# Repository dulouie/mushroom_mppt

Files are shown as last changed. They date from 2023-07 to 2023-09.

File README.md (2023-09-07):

# Mushroom MPPT Controller
The mushroom controller, is a micropython powered mppt solar optimizer to investigate different algorithms.

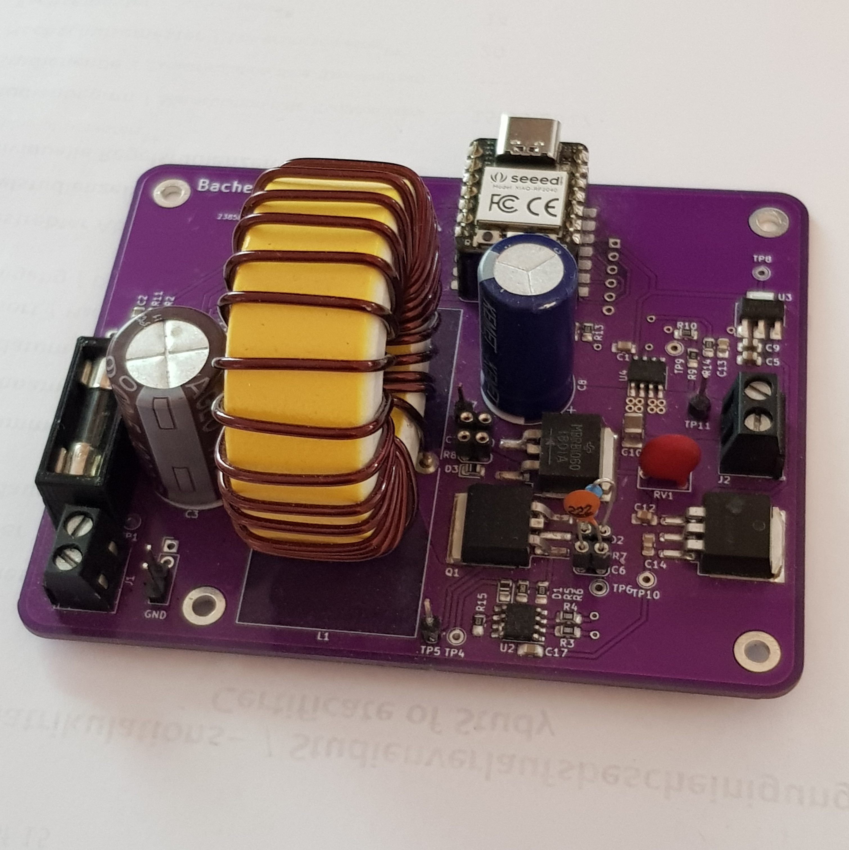
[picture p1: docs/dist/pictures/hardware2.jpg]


You can find a great overview of the project on this [slides](https://dulouie.github.io/mushroom_mppt/) or read the project [documentation](https://dulouie.github.io/mushroom_mppt_doc/).

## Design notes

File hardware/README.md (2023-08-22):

# Hardware

Here you will find the information to build the Mushroom MPPT controller. The schematic and the board layout is a KiCAD 7 project. 

Layout

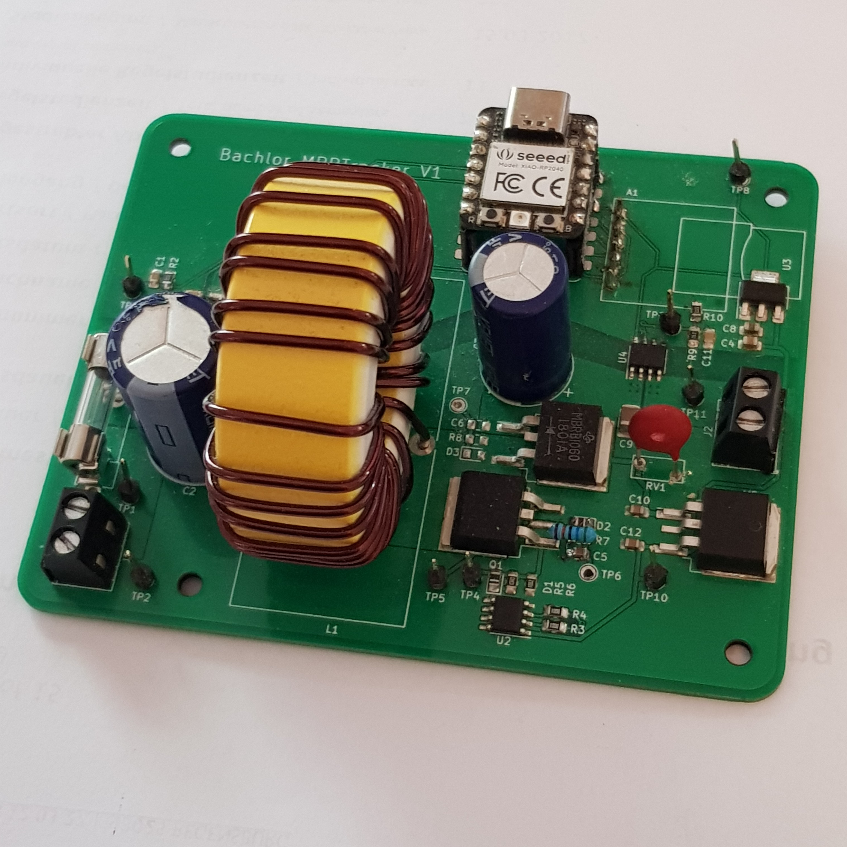
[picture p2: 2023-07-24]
docs/dist/pictures/hardware1.jpg

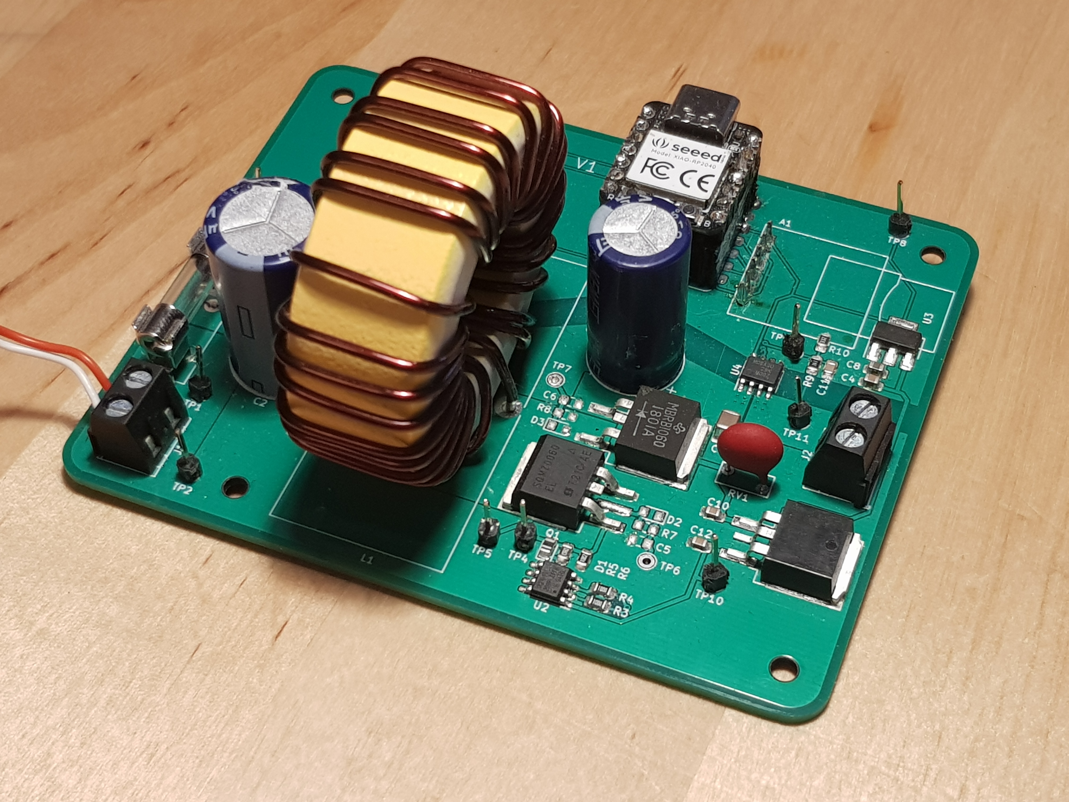
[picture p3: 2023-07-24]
slides/dist/pictures/hardware_alt.jpg

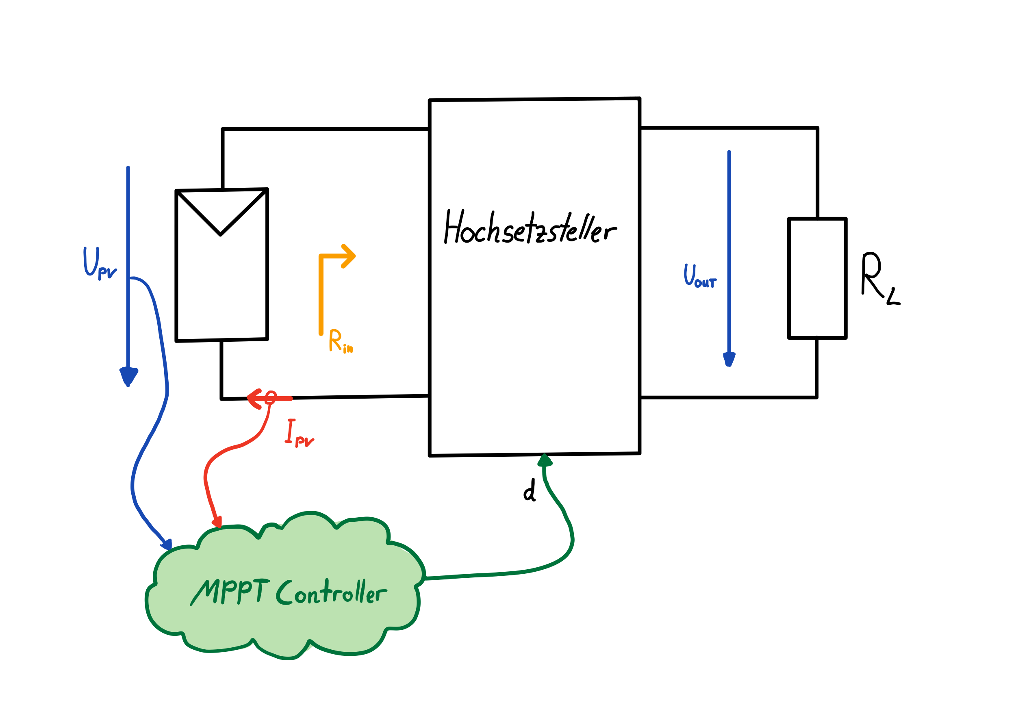
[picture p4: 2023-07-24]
docs/dist/pictures/konzept5.png

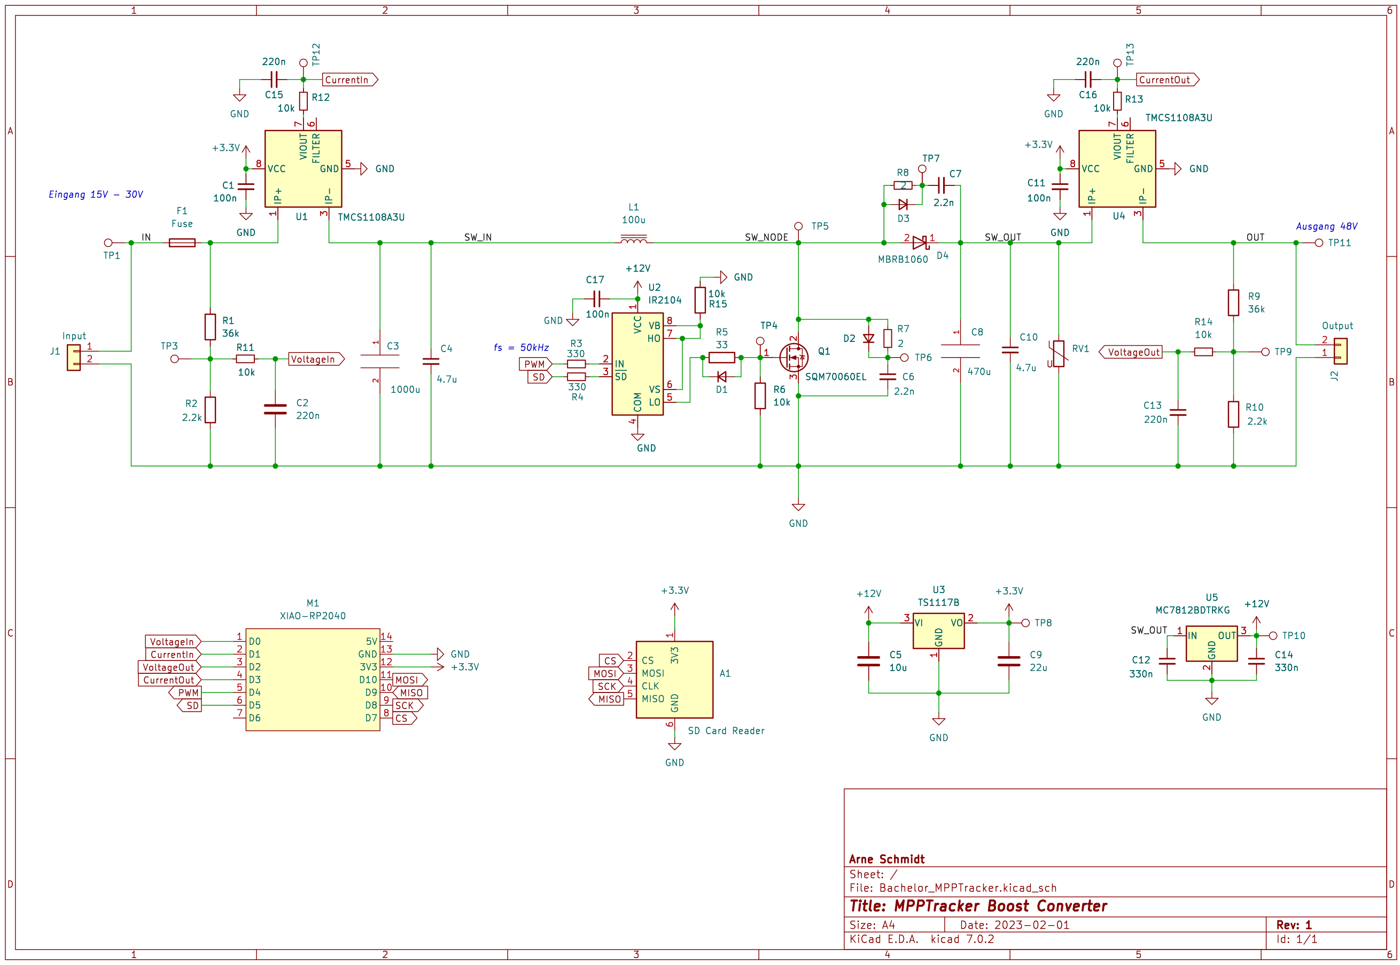
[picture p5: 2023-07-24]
docs/dist/pictures/schaltplan_final.png

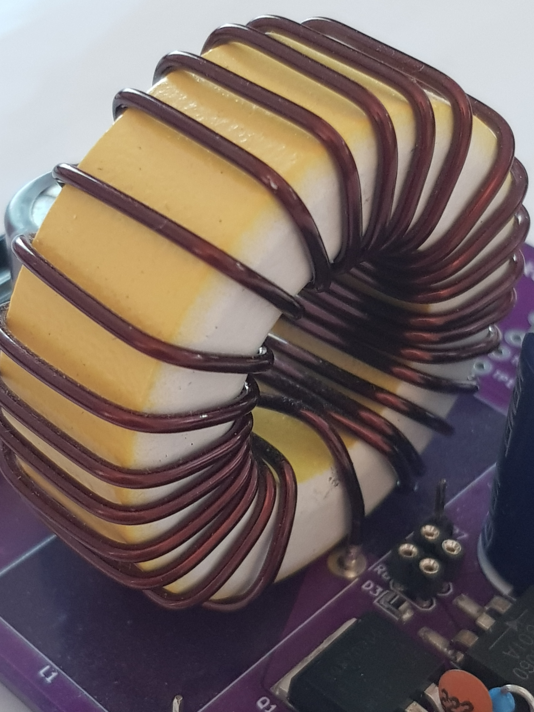
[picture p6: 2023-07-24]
docs/dist/pictures/spule.jpg

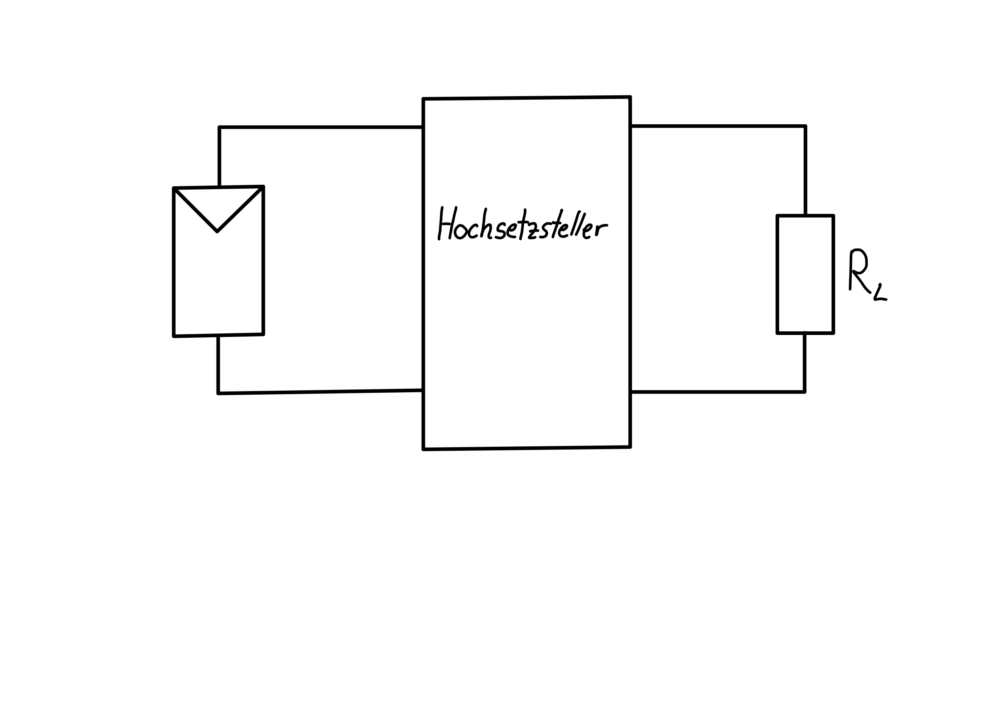
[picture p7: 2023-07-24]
docs/dist/pictures/konzept3.png

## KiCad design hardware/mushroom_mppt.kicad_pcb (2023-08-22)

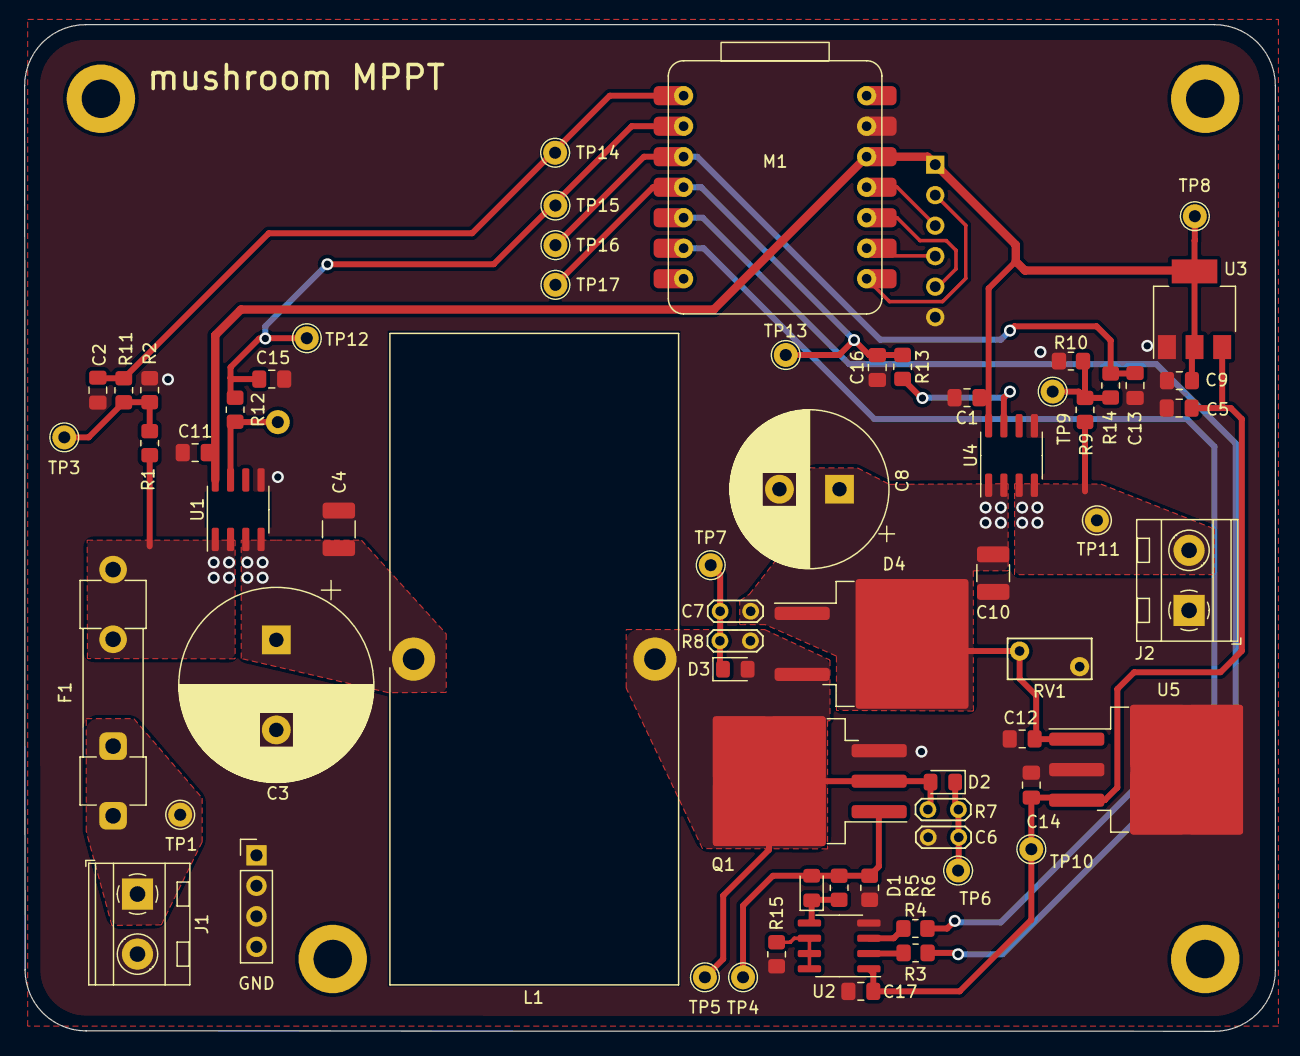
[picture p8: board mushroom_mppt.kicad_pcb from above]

Board: 2 copper layers, 104.1 x 83.8 mm, 66 parts (1 on the bottom side), 30 nets.

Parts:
A1: SD Card Reader; SD_Card_Module
C1, C11, C17: 0.1u; C_0805_2012Metric_Pad1.18x1.45mm_HandSolder
C2, C13, C15, C16: 220n; C_0805_2012Metric_Pad1.18x1.45mm_HandSolder
C3: 1000u; CP_Radial_D16.0mm_P7.50mm
C4: 4,7u; C_1210_3225Metric_Pad1.33x2.70mm_HandSolder
C5: 10u; C_0805_2012Metric_Pad1.18x1.45mm_HandSolder
C6, C7: C_snubber; TestPoint_2Pads_Pitch2.54mm_Drill0.8mm
C8: 470u; CP_Radial_D13.0mm_P5.00mm
C9: 22u; C_0805_2012Metric_Pad1.18x1.45mm_HandSolder
C10: 4.7u; C_1210_3225Metric_Pad1.33x2.70mm_HandSolder
C12, C14: 0.33u; C_0805_2012Metric_Pad1.18x1.45mm_HandSolder
D1: D_gatedriver; D_0805_2012Metric_Pad1.15x1.40mm_HandSolder
D2, D3: snubber; D_0805_2012Metric_Pad1.15x1.40mm_HandSolder
D4: MBRB1060; TO-263-2_TabPin1
F1: Fuse; Fuseholder_Clip-5x20mm_Littelfuse_520_Inline_P20.50x5.80mm_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
GND: TestPoint; PinHeader_1x04_P2.54mm_Vertical
J1: Input; TerminalBlock_MetzConnect_Type094_RT03502HBLU_1x02_P5.00mm_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
J2: Output; TerminalBlock_MetzConnect_Type094_RT03502HBLU_1x02_P5.00mm_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
L1: 100u; L_Toroid_Vertical_L54.0mm_W23.8mm_P20.10mm_Bourns_5700
M1: XIAO-RP2040
Q1: SQM70060EL; TO-263-3_TabPin2
R1, R9: 36k; R_0805_2012Metric_Pad1.20x1.40mm_HandSolder
R2, R10: 2.2k; R_0805_2012Metric_Pad1.20x1.40mm_HandSolder
R3, R4: 100; R_0805_2012Metric_Pad1.20x1.40mm_HandSolder
R5: 10; R_0805_2012Metric_Pad1.20x1.40mm_HandSolder
R6, R11, R12, R13, R14, R15: 10k; R_0805_2012Metric_Pad1.20x1.40mm_HandSolder
R7, R8: snubber; TestPoint_2Pads_Pitch2.54mm_Drill0.8mm
RV1: type="I" model="Varistor" lib=""; RV_Disc_D7mm_W3.4mm_P5mm
TP1, TP3, TP4, TP5, TP6, TP7, TP8, TP9, TP10, TP11, TP12, TP13, TP14, TP15, TP16, TP17: TestPoint; TestPoint_THTPad_D2.0mm_Drill1.0mm
U1, U4: TMCS1108A3U; SOIC-8_3.9x4.9mm_P1.27mm
U2: IR2104; SOIC-8_3.9x4.9mm_P1.27mm
U3: TS1117B; SOT-223-3_TabPin2
U5: MC7812BDTRKG; TO-263-3_TabPin2

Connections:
+3.3V: A1.1 (3V3), C1.1, C9.1, C11.1, M1.12 (3V3), TP8.1, U1.8 (VCC), U3.2 (VO), U4.8 (VCC)
+12V: C5.1, C14.1, C17.1, TP10.1, U2.1 (VCC), U3.3 (VI), U5.3 (OUT)
/OUT: J2.2, R9.1, TP11.1, U4.3 (IP-), U4.4 (IP-)
/SW_IN: C3.1, C4.1, L1.1, U1.3 (IP-), U1.4 (IP-)
/SW_NODE: D2.2 (A), D3.2 (A), D4.2 (A), L1.2, Q1.2 (D), R7.1, R8.1, TP5.1
/SW_OUT: C7.2, C8.1, C10.1, C12.1, D4.1 (K), RV1.1, U4.1 (IP+), U4.2 (IP+), U5.1 (IN)
CS: A1.2 (CS), M1.8 (D7)
CurrentIn: C15.2, M1.2 (D1), R12.1, TP12.1, TP15.1
CurrentOut: C16.2, M1.4 (D3), R13.1, TP13.1, TP17.1
GND: A1.6 (GND), C1.2, C2.2, C3.2, C4.2, C5.2, C6.2, C8.2, C9.2, C10.2, C11.2, C12.2, C13.2, C14.2, C15.1, C16.1, C17.2, GND.1, GND.2, GND.3, GND.4, J1.2, J2.1, M1.13 (GND), Q1.3 (S), R2.2, R6.2, R10.2, R15.1, RV1.2, U1.5 (GND), U2.4 (COM), U3.1 (GND), U4.5 (GND), U5.2 (GND)
IN: F1.1, J1.1, TP1.1
MISO: A1.5 (MISO), M1.10 (D9)
MOSI: A1.3 (MOSI), M1.11 (D10)
unnamed: D1.2 (A), Q1.1 (G), R5.2, R6.1, TP4.1
unnamed: D1.1 (K), R5.1, U2.5 (LO)
unnamed: C6.1, D2.1 (K), R7.2, TP6.1
unnamed: C7.1, D3.1 (K), R8.2, TP7.1
unnamed: F1.2, R1.1, U1.1 (IP+), U1.2 (IP+)
unnamed: R1.2, R2.1, R11.1, TP3.1
unnamed: R9.2, R10.1, R14.2, TP9.1
unnamed: R12.2, U1.7 (VIOUT)
unnamed: R15.2, U2.6 (VS), U2.7 (HO), U2.8 (VB)
unnamed: R3.2, U2.2 (IN)
unnamed: R4.2, U2.3 (~SD)
unnamed: R13.2, U4.7 (VIOUT)
PWM: M1.5 (D4), R3.1
SCK: A1.4 (CLK), M1.9 (D8)
SD: M1.6 (D5), R4.1
VoltageIn: C2.1, M1.1 (D0), R11.2, TP14.1
VoltageOut: C13.1, M1.3 (D2), R14.1, TP16.1

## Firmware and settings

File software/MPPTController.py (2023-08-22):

from machine import Pin, PWM, ADC, Timer
from singleton import singleton
from FilterAvg import FilterAvg
from PID import PID

rounded = 3
adcScaleFac = 3.2 / 2**16  		    # 3.3V / 2^16 (bit)
voltDiv = 36 / 2.2		            # voltage divider input stage 36k / 4.7k
currentSensivity = 0.2		    	# TMCS1108A3U 200mV/A
zeroCurrentHall = 3.2 * 0.1     	# datasheet suppy voltage * 0.1
corr = (1.117,                      # correction factor for all ADCs
        1.026,                        # voltage in, current in, voltage out, current out
        1.117,
        1.015)

@singleton
class MPPTController():
    ''' Hardware abtraction layer for MPPTController'''
    def __init__(self):
        self.pwm = PWM(Pin(6, Pin.OUT))
        self.pwm.freq(50000) 
        self.sd = Pin(7, Pin.OUT)
        self.adc1 = ADC(Pin(26, Pin.IN))
        self.adc2 = ADC(Pin(27, Pin.IN))
        self.adc3 = ADC(Pin(28, Pin.IN))
        self.adc4 = ADC(Pin(29, Pin.IN))
        self.filter1 = FilterAvg(adc=self.adc1, samples=50)
        self.filter2 = FilterAvg(adc=self.adc2, samples=50)
        self.filter3 = FilterAvg(adc=self.adc3, samples=50)
        self.filter4 = FilterAvg(adc=self.adc4, samples=50)
        self.filtered = [0.,0.,0.,0.]
        self.voltage = [0.,0.]
        self.current = [0.,0.]
        self.power = [0.,0.]
        self.efficiency = 0.
        self.duty = 0
        self.vRef = 0
        self.pid = PID(scale='ms')

    def shutdown(self, s: bool):
        '''Shutdown the mosfet driver'''
        if s is True:
            self.sd.off()
        else:
            self.sd.on()

    def setpidTuning(self,kp, ki, kd):
        '''Set pid tunings for output controller'''
        self.pid.tunings = (kp, ki, kd)

    def printOut(self):
        '''Print all voltages, currents and power to console'''
        print("duty:{} IN:{}V/{}A {}W OUT:{}V/{}A vRef:{} eff:{}".format(self.duty,
                                                    self.voltage[0],
                                                    self.current[0], 
                                                    self.power[0], 
                                                    self.voltage[1], 
                                                    self.current[1],
                                                    self.vRef,
                                                    self.efficiency))
        
    def setDutyCycle(self, duty):
        '''Set mosfet dutycycle for boost converter'''
        self.duty = int(((100 - duty) / 100) * 65536)
        self.pwm.duty_u16(self.duty)

    def getfilteredADC(self):
        '''Sample and filter adc data'''
        self.filtered[0] = self.filter1.calc()
        self.filtered[1] = self.filter2.calc()
        self.filtered[2] = self.filter3.calc()
        self.filtered[3] = self.filter4.calc()

        return(self.filtered)

    def calcADCData(self):
        '''Calcuate raw adc data to voltages and currents'''
        self.voltage[0] = round(corr[0]*self.filtered[0]*adcScaleFac*voltDiv, rounded)
        self.voltage[1] = round(corr[2]*self.filtered[2]*adcScaleFac*voltDiv, rounded)
        self.current[0] = round(corr[1]*(((self.filtered[1] *
                                                adcScaleFac) - zeroCurrentHall) / 
                                                currentSensivity), rounded)
        self.current[1] = round(corr[3]*(((self.filtered[3] *
                                                adcScaleFac) - zeroCurrentHall) /
                                                currentSensivity), rounded)
        self.power[0] = round(self.voltage[0] * self.current[0], rounded)
        self.power[1] = round(self.voltage[1] * self.current[1], rounded)
        self.efficiency = round(self.power[1] / self.power[0], rounded)

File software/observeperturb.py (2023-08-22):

from MPPTController import MPPTController
import time

def clamp(vRef):
    '''clamp vRef voltage'''
    if vRef <= 0:
        vRef = 0
    elif vRef >= 70:
        vRef = 70
    return vRef

device = MPPTController()
device.shutdown(True)
time.sleep_ms(1000)
device.shutdown(False)

power = 0.
voltage_delta = 0.
power_delta = 0.
voltage_pre = 0.
power_pre = 0.
device.setDutyCycle(0)
time.sleep(1)

while(True):
    device.getfilteredADC()
    device.calcADCData()
    power_delta = device.power[0] - power_pre
    voltage_delta = device.voltage[0] - voltage_pre
    power_pre = device.power[0]
    voltage_pre = device.voltage[0]

    if power_delta >= 0:
        if voltage_delta > 0:
            device.vRef -= 1
        else:
            device.vRef += 1
    elif power_delta < 0:
        if voltage_delta > 0:
            device.vRef += 1
        else:
            device.vRef -= 1
            
    device.vRef = clamp(device.vRef)
    device.setDutyCycle(device.vRef)
    device.printOut()
    time.sleep_ms(100)
